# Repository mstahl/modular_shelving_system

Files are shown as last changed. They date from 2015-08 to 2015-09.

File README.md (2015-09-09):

Modular Shelving System
=======================
Building upon ideas I found around Thingiverse but mostly from
[FatalError3141](http://www.thingiverse.com/thing:398548)'s excellent Parts
Tray Drawers, I wanted to be able to print more sets of drawers and interlock
them somehow.

This is still a work in progress. The outer frame modules are pretty much set,
but I'm still experimenting with what the drawers should look like.

## Usage

To make a wide variety of STLs for modules from 1x1 to 3x3,

    $ ruby ./build.sh

...and _shazam!_ now the build directory is filled with STLs you can use. This
is also how the files on Thingiverse are generated for each release.

If you instead want to make your own module STLs, you can do so by using OpenSCAD's
`-D` option,

    $ openscad -D MODULE_WIDTH=5 -D MODULE_HEIGHT=2 -D GENERATE_UNIT=1 ./drawer_module.scad -o 5x2-unit.stl
    $ openscad -D MODULE_WIDTH=3 -D MODULE_HEIGHT=6 -D GENERATE_DRAWER=1 ./drawer_module.scad -o 3x6-drawer.stl

...to make a 5x2 unit and a 3x6 drawer. The allowable options are....

| Option | Purpose | Values allowed |
| --- | --- | --- |
| `MODULE_WIDTH` | Width in module units | 1, 2, 3, ... |
| `MODULE_HEIGHT` | Height in module units | 1, 2, 3, ... |
| `GENERATE_UNIT` | Set to 1 to make a unit | 0 or 1 |
| `GENERATE_DRAWER` | Set to 1 to make a drawer | 0 or 1 |

_Important note:_ Don't set both `GENERATE_UNIT` and `GENERATE_DRAWER` at the
same time. Your unit and drawer will be combined into the same thing and they
will look jacked up.

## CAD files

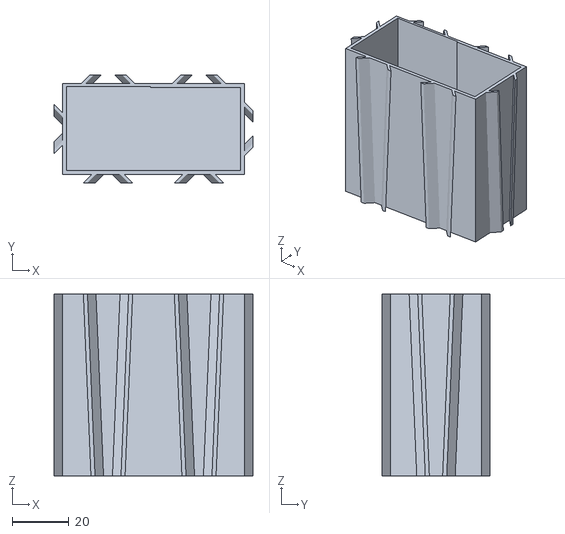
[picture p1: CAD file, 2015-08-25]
build/unit1x2.stl
70.0 x 38.0 x 64.0

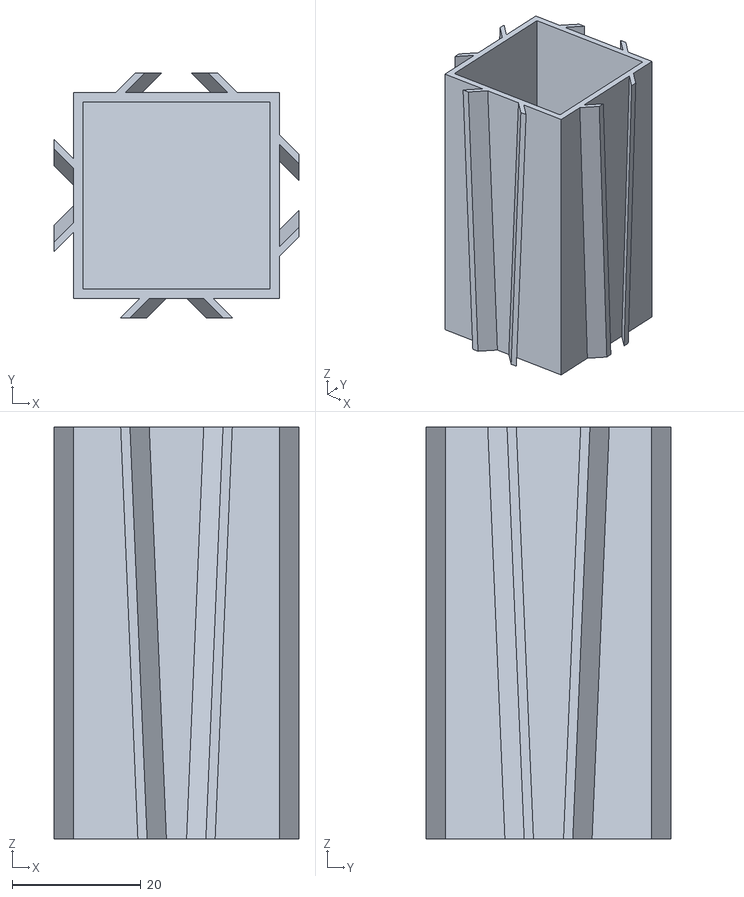
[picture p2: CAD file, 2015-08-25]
build/unit1x1.stl
38.0 x 38.0 x 64.0

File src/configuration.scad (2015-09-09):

/*
 * configuration.scad
 *
 * Part of the Modular Drawer System.
 *
 * (c) 2015 max thom stahl. Released under the Creative Commons Share-Alike
 * license. See LICENSE for details.
 */

//--[ Unit sizes ]--------------------------------------------------------------

UNIT_X = 32.0; // These set the width/height/depth of the smallest possible
UNIT_Y = 32.0; // module for this system.
UNIT_Z = 64.0;

//--[ Global wall thickness ]---------------------------------------------------

calculated_extrusion_width = 0.48;
WALL_THICKNESS = calculated_extrusion_width * 3;

//--[ Drawer sizes ]------------------------------------------------------------

DRAWER_GAP = 0.5;
LIP = 1.0;
DRAWER_WALL_THICKNESS = 2*calculated_extrusion_width;

//--[ Drawer dividers ]---------------------------------------------------------

DIVIDER_WIDTH = 2*calculated_extrusion_width;

//--[ Connector settings ]------------------------------------------------------

GROOVE_W_TOP = UNIT_Y / 2;
GROOVE_W_BOTTOM = UNIT_Y / 3;
GROOVE_DEPTH = 3.0;

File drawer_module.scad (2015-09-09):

/*
 * drawer_module.scad
 *
 * Part of the Modular Drawer System.
 *
 * See comments for how to customize.
 *
 * (c) 2015 max thom stahl. Released under the Creative Commons Share-Alike
 * license. See LICENSE for details.
 */

include <src/configuration.scad>
include <src/connectors.scad>
include <src/drawers.scad>
include <src/drawer_dividers.scad>
include <src/units.scad>

MODULE_WIDTH = 1;
MODULE_HEIGHT = 1;

GENERATE_UNIT = 0;
GENERATE_DRAWER = 0;

DEMO = 0;

if (GENERATE_UNIT == 1) {
  unit(w=MODULE_WIDTH, h=MODULE_HEIGHT);
}
if (GENERATE_DRAWER == 1) {
  drawer(w=MODULE_WIDTH, h=MODULE_HEIGHT);
}

module demo() {
  unit(1,1);
  translate([UNIT_X + GROOVE_DEPTH, 0, 0])
    unit(1,1);
  translate([0, UNIT_Y + GROOVE_DEPTH, 0])
    unit(2,2);

  translate([2*UNIT_X + 2*GROOVE_DEPTH, UNIT_Y + GROOVE_DEPTH, 0])
    unit(1,1);
  translate([2*UNIT_X + 2*GROOVE_DEPTH, 2*(UNIT_Y + GROOVE_DEPTH), 0])
    unit(1,1);
}

if (DEMO == 1) {
  demo();
}

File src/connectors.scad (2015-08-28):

/*
 * connectors.scad
 *
 * Part of the Modular Drawer System.
 *
 * (c) 2015 max thom stahl. Released under the Creative Commons Share-Alike
 * license. See LICENSE for details.
 */

include <configuration.scad>

module connector(w_top, w_bottom) {
  difference() {
    polyhedron(points=[
      [0, -w_top/2 - WALL_THICKNESS, UNIT_Z],                         // [0]
      [0, w_top/2 + WALL_THICKNESS, UNIT_Z],                          // [1]
      [GROOVE_DEPTH, w_top/2-GROOVE_DEPTH + WALL_THICKNESS, UNIT_Z],  // [2]
      [GROOVE_DEPTH, -w_top/2+GROOVE_DEPTH - WALL_THICKNESS, UNIT_Z], // [3]
      [0, -w_bottom/2 - WALL_THICKNESS, 0],                           // [4]
      [GROOVE_DEPTH, -w_bottom/2+GROOVE_DEPTH - WALL_THICKNESS, 0],   // [5]
      [GROOVE_DEPTH, w_bottom/2-GROOVE_DEPTH + WALL_THICKNESS, 0],    // [6]
      [0, w_bottom/2 + WALL_THICKNESS, 0]                             // [7]
    ], faces=[
      [0,3,5,4], [5,6,7,4], [6,2,1,7], [0,1,2,3], [3,2,6,5], [1,0,4,7]
    ]);
    polyhedron(points=[
      [0, -w_top/2, UNIT_Z],                         // [0]
      [0, w_top/2, UNIT_Z],                          // [1]
      [GROOVE_DEPTH, w_top/2-GROOVE_DEPTH, UNIT_Z],  // [2]
      [GROOVE_DEPTH, -w_top/2+GROOVE_DEPTH, UNIT_Z], // [3]
      [0, -w_bottom/2, 0],                           // [4]
      [GROOVE_DEPTH, -w_bottom/2+GROOVE_DEPTH, 0],   // [5]
      [GROOVE_DEPTH, w_bottom/2-GROOVE_DEPTH, 0],    // [6]
      [0, w_bottom/2, 0]                             // [7]
    ], faces=[
      [0,3,5,4], [5,6,7,4], [6,2,1,7], [0,1,2,3], [3,2,6,5], [1,0,4,7]
    ]);
  }
}

module connector_female() {
  connector(GROOVE_W_TOP, GROOVE_W_BOTTOM, GROOVE_DEPTH);
}

module connector_male() {
  scale([-1,1,1])
    connector(GROOVE_W_TOP - 2*WALL_THICKNESS - 0.5, GROOVE_W_BOTTOM - 2*WALL_THICKNESS - 0.5, GROOVE_DEPTH);
}

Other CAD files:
src/drawer_dividers.scad
src/drawers.scad
src/units.scad

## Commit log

2015-08-22 Initial commit y'all
    [frame1x1.scad]
2015-08-23 Thicker walls, broken Makefile
    The makefile doesn't work and I'm not super sure why. I'm no good at
    makefiles actually. Don't tell anyone.
    [frame1x1.scad]
2015-08-23 Organized reusable code
    The outer frame is constant from module to module. Only the inner
    cutouts change from model to model.
    [configuration.scad, frame1x2.scad]
2015-08-24 Gonna radically change this for v1.0 using what I've learned here.
    [configuration.scad, frame1x1.scad, frame2x2.scad]
2015-08-25 v1.0 design finished
    This is the first release candidate for v1.0. I've changed the units
    around so that each one always has just one drawer, and different units
    may be made arbitrarily in sizes that are multiples of some unit length,
    which in this case is 32mm. The way the units are designed, 2x2 units
    may be arbitrarily combined with 1x1, 4x1, whatever, to make a fully
    custom shelving unit.
    [configuration.scad, connectors.scad, frame1x1.scad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]
2015-08-25 Full customization achieved!
    The whole thing happens in `drawer_module.scad` now. A call to `unit(w,
    h)` creates a single module `w` units wide by `h` units high. Units
    right now are 32x32x64mm.
    [drawer_module.scad, drawers.scad, unit1x2.stl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]
2015-08-25 I really don't know how to write makefiles
    So I wrote a quick and durrrty Ruby build script instead. If you're in
    Linux, you'll probably have to change a line or two in there.
    [drawer_module.scad, module-1x1.stl, module-2x1.stl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]
2015-08-25 Built ALL THE DRAWERS
    [drawer-1x1.stl, drawer-1x2.stl, drawer-1x3.stl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]
2015-08-26 Some minor adjustments
    The cutout for the drawers in the units was slightly off, so two walls
    along the outside were printing thinner than the other two. I wanted
    those to be juuuuuust over the wall gap fill threshold for my software,
    to make sure the walls are all solid, so those have now been adjusted.
    Also, the connector tabs were the wrong distance apart on the male
    connector, so the units could only slide together 2/3 of the way then
    get stuck.
    [connectors.scad, drawer-1x3.stl, drawer-1x4.stl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]
2015-08-28 Finished out units, worked on drawers
    [configuration.scad, connectors.scad, drawer-1x1.stl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]
2015-08-28 Fixed connectors, added lip
    The lip is to keep the drawers in place while they're inside the module,
    without disrupting your ability to move the drawer.
    [drawer-1x1.stl, drawer-1x2.stl, drawer-1x3.stl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]
2015-09-09 Fixed large module errors
    Cleaned up the lip and dimensions of the larger units so that they will
    all fit together properly.
    [configuration.scad, drawer-1x1.stl, drawer-1x2.stl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]
